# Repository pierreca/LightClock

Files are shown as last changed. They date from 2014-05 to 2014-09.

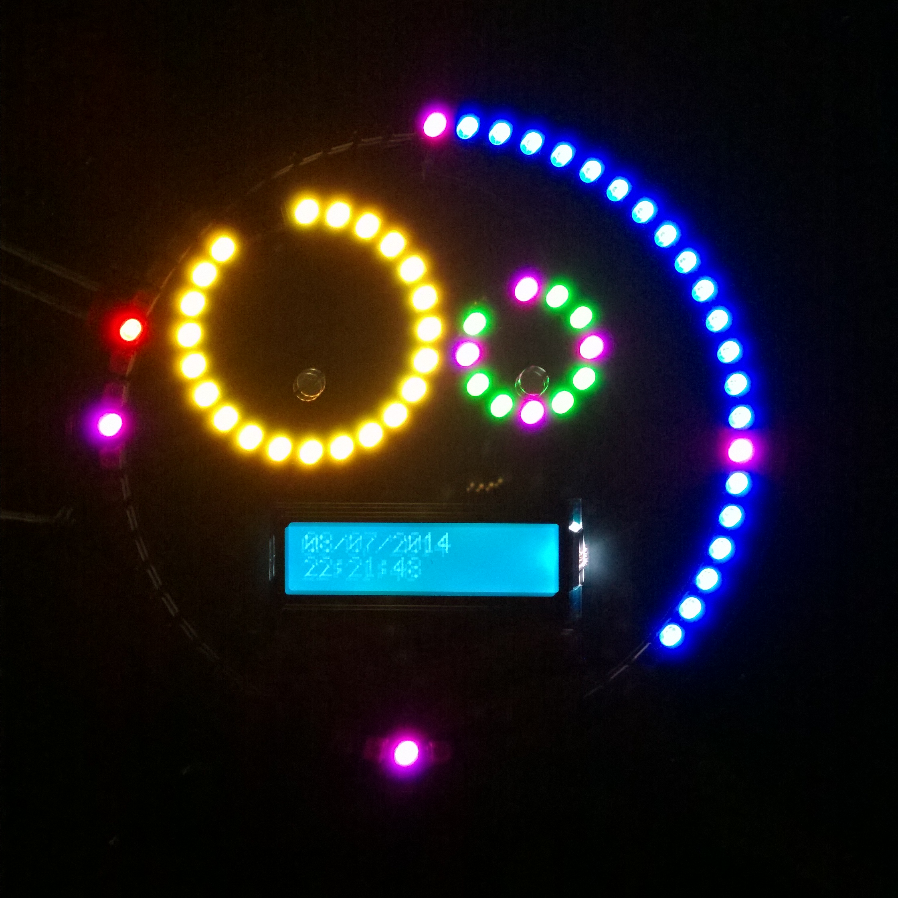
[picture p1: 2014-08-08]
blurrypic.jpg

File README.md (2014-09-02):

LightClock is a simple clock project.

LightClock Blurry Pic

#Hardware#
* [Arduino Uno R3](http://www.adafruit.com/products/50 "Arduino Uno R3")
* [LCD Shield](http://www.adafruit.com/products/714)
* Adafruit NeoPixels Rings ([12](http://www.adafruit.com/products/1643), [24](http://www.adafruit.com/products/1586) and [60](http://www.adafruit.com/products/1768) LEDs)
* [Chronodot](http://www.adafruit.com/products/255)
* [Parallax PIR Sensor](http://www.parallax.com/product/555-28027)
* [Adafruit Weatherproof Pushbutton (Momentary)](https://www.adafruit.com/products/481)
* [Adafruit Weatherproof Pushbutton (On/Off)](https://www.adafruit.com/products/915)

#Chassis#
Made of smoke laser-cut acrylic. It's a very bad design that constantly falls appart and is a pain to assemble.

#Features#
* Displays the time (it's a clock!)
	* Minutes and Seconds on the outer ring
	* Hours (on the inner rings)
	* Date and Time on the LCD screen
* Time can be set with the buttons of the LCD shield.
* Keeps time even when not plugged thanks to the Chronodot battery
* Clock stays on for 30 minutes then turns off. any movement detected by the PIR sensor will wake it up.
* Front button enables/disable wake up from PIR sensor (for night time for example)
* Back button acts as a regular on/off button

#In Progress#
(see other branches)
* PIR sensor to detect movement and light up/down
* Button to override PIR sensor

#Ideas for the future#
* Redesign chassis to be easier to assemble/disassemble and more sturdy.
* Alarm Clock (add a buzzer?)
* On/Off hours (dim or turn off at night)
* Add a potentiometer to control LEDs intensity
* Add some connectivity and a "Control app" to set things like colors and alarms.

#Links#
* <http://www.hackster.io/pierreca/lightclock>
* <https://hackaday.io/project/2330-LightClock>

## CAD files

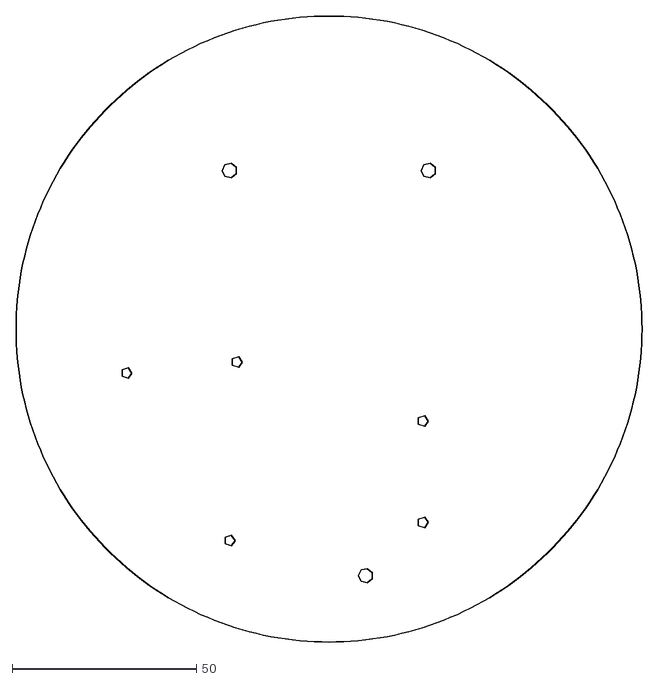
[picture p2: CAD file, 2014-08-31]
Case/Backplate.dxf
170.0 x 170.0

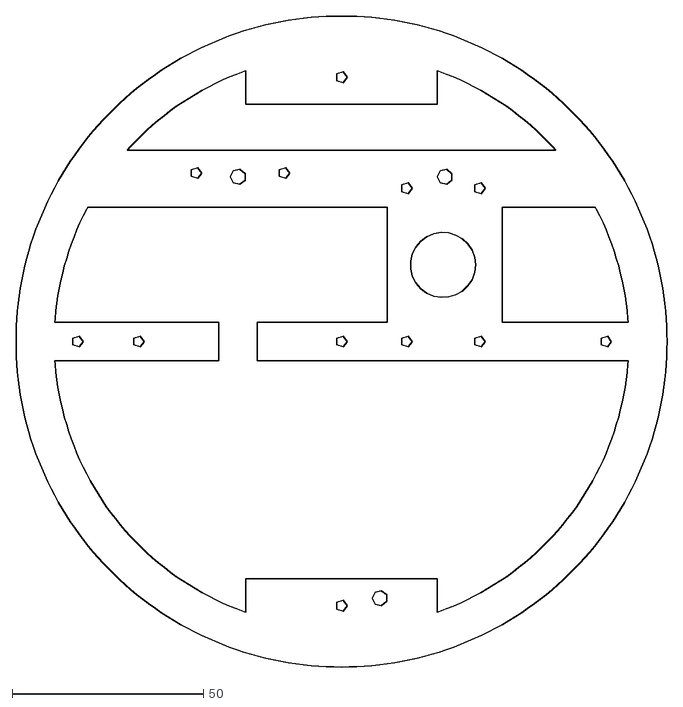
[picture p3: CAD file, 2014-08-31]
Case/RingsBackPlate.dxf
170.0 x 170.0

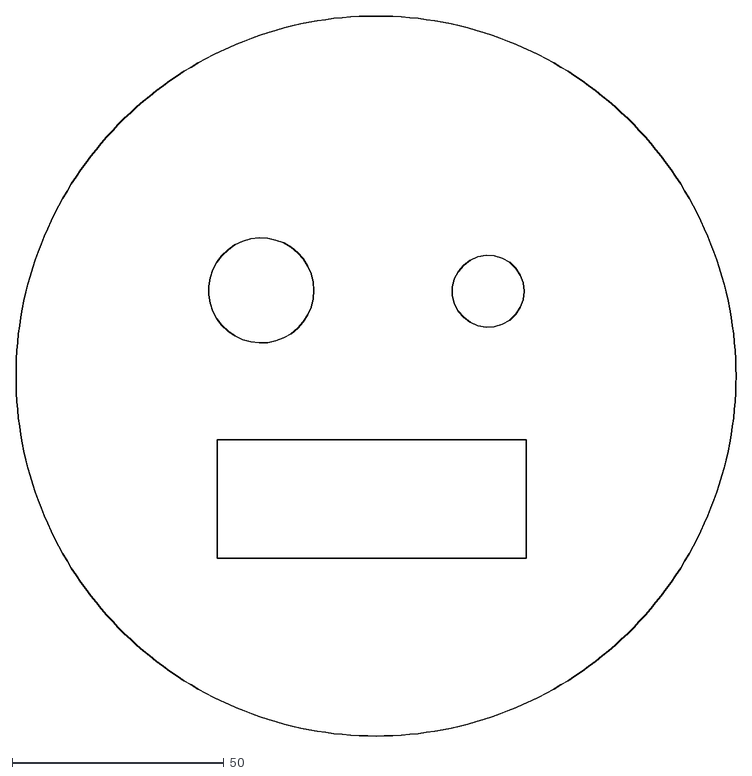
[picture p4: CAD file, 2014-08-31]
Case/Frontplate.dxf
170.0 x 170.0

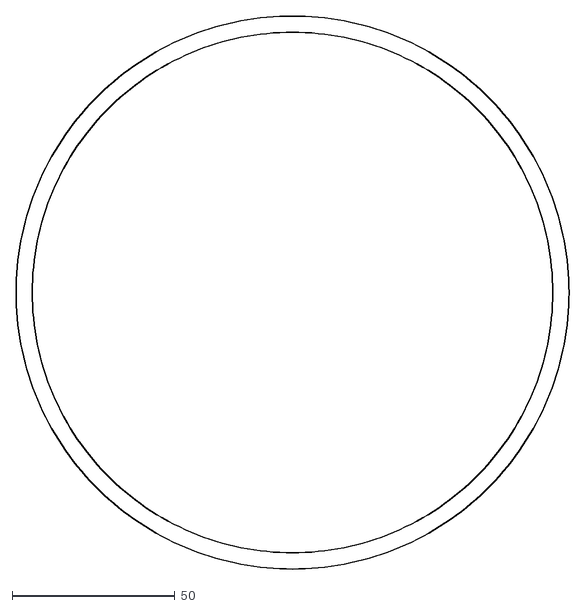
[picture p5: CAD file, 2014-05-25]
Case/SideRing.dxf
170.0 x 170.0

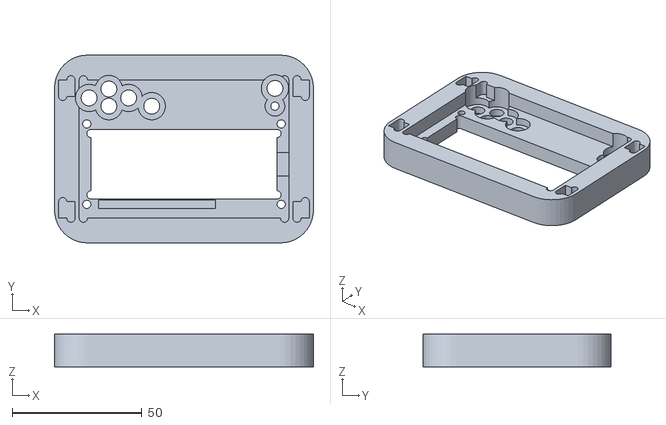
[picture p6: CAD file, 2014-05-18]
Case/faceplate.STL
99.8 x 72.4 x 12.7

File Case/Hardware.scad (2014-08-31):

// Screws and Spacers for the LightClock project
//
// Pierre Cauchois (pierreca)
// 5/18/2014

module spacer(x,y,z) {
	spacer_generic(x, y, z, 10);
}

module short_spacer(x, y, z) {
	spacer_generic(x, y, z, 3);
}

module spacer_generic(x, y, z, length) {
	color("black")
	translate([x,y,z]) {
		difference() {
			cylinder(h = length, r = 3.5);
			cylinder(h = length, r = 1.5);
		}
	}
}

module big_spacer(x,y,z) {
	color("silver")
	translate([x,y,z]) {
		difference() {
			cylinder(h = 20, r = 4.5);
			cylinder(h = 20, r = 2);
		}
	}
}

module screw (x,y,z) {
	screw_generic(x, y, z, 20);
}

module long_screw (x,y,z) {
	color("silver")
	translate([x,y,z]) {
		difference() {
			union () {
				cylinder(h = 50, r = 2);
				cylinder(h = 2.5, r = 3.5);
			}
			translate([-4, -0.5, -0.5]) cube(size=[8, 1, 1]);
		}
	}
}

module short_screw (x,y,z) {
	screw_generic(x, y, z, 8);
}

module screw_generic (x,y,z,length) {
	color("silver")
	translate([x,y,z]) {
		difference() {
			union() {
				cylinder(h = length, r = 1.5);
				cylinder(h = 2, r = 2.5);
			}
			translate([-3, -0.5, -0.5]) cube(size=[6, 1, 1]);
		}
	}
}

screw(10,0,0);
spacer(10,0,3);

long_screw(0,0,0);
big_spacer(0,0,4);

short_screw(20, 0, 0);
short_spacer(20, 0, 3);

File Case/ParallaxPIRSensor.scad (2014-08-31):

pcb_thickness = 1.75;
pcb_width = 36;
pcb_height = 25;

sensor_base_width = 23;
sensor_base_thickness = 3.2;
sensor_orb_radius = 11.4;

module pcb (x, y, z) {
	translate([x, y, z]) {
		difference() {
			color("teal") cube(size=[pcb_width, pcb_height, pcb_thickness]);		
			translate([2.5, 13, -0.5]) cylinder(h = pcb_thickness + 1, r = 1.15);
			translate([32.5, 13, -0.5]) cylinder(h = pcb_thickness + 1, r = 1.15);
		}
	}
}

module sensor (x, y, z) {
	translate([x, y, z]) {
		color("white") 
		union() {
			cube(size=[sensor_base_width, sensor_base_width, sensor_base_thickness]);
			translate([sensor_orb_radius, sensor_orb_radius, sensor_base_thickness])
			difference() {
				sphere(sensor_orb_radius); // for normal rendering
				//cylinder(h = 20, r = sensor_orb_radius); // helps for laser cutting
				translate([-(sensor_orb_radius + 0.5), -(sensor_orb_radius + 0.5), -(2*sensor_orb_radius + 1)]) cube(size=[2*sensor_orb_radius + 1, 2*sensor_orb_radius + 1, 2*sensor_orb_radius + 1]);
			}
		}		
	}
}

module jumper (x, y, z) {
	translate([x, y, z]) {	
		color("black") cube(size=[2, 6, 6]);
	}
}

module connector (x, y, z) {
	translate([x, y, z]) {	
		color("black") cube(size=[7.5, 8.5, 2]);
	}
}


module pir_sensor (x, y, z) {
	translate([x, y, z]) {
		pcb(0,0,0);
		sensor(6, 0.8, pcb_thickness);	
		jumper(1, 17, -6);	
		connector(14,-6.6,-2);
	}
}

pir_sensor(0,0,0);

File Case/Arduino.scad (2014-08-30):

// Arduino Components for the LightClock project
//
// Pierre Cauchois (pierreca)
// 5/18/2014

pcb_thickness = 1.75;

module button(x, y) {
	translate([x,y,0]) {
		color("silver") cube(size=[6, 6, 3.5]);
		color("black") translate([3, 3, 0]) cylinder(h=5, r=1.5);
	}
}

module buttons(x, y, z) {
	translate([x, y, z]) {
		button(x, y + 4);
		button(x + 8, y);
		button(x + 8, y + 7);
		button(x + 16, y + 4);
		button(x + 24, y + 7);
		button(x + 72.5, y);
	}
}

module lcd_16x2(x, y, z) {
	translate([x, y, z]) {
		color("darkgrey") difference () {
			cube(size=[73, 28, 9]);
			translate([3.5, 5, 8.6]) cube(size=[66, 18, 0.5]);
		}
		color("darkgreen") translate([3.5, 5, 8.4]) cube(size=[66, 18, 0.5]);
	}
}

module pcb(width_x, height_y) {
	color("teal") cube(size=[width_x, height_y, pcb_thickness]);
}

module arduino (x, y, z) {
	translate([x, y, z]) {
		difference() {
			pcb(68.5, 53); 	// Arduino PCB (w/ screw holes)
			translate([13.5,2.5,0]) cylinder(h=2, r=1.5);
			translate([66,7.5,0]) cylinder(h=2, r=1.5);
			translate([66,35,0]) cylinder(h=2, r=1.5);
			translate([15,51,0]) cylinder(h=2, r=1.5);
		}
		color("silver") translate([-6, 32, pcb_thickness]) cube (size=[16, 12, 11]); // USB port
		color("black") translate([-2, 1, pcb_thickness]) cube (size=[13.5, 8.5, 11]); // Power jack
		color("black") translate([26, 1, pcb_thickness]) cube (size=[21, 2.5, 8.5]); // Header
		color("black") translate([49, 1, pcb_thickness]) cube (size=[16, 2.5, 8.5]); // Header
		color("black") translate([17, 49.5, pcb_thickness]) cube (size=[26, 2.5, 8.5]); // Header
		color("black") translate([44, 49.5, pcb_thickness]) cube (size=[21, 2.5, 8.5]); // Header
	}
}

module adafruit_lcd_shield_base(x, y, z) {
	translate([x, y, z]) {
		pcb(81, 54); // base PCB
		buttons(0, 0, pcb_thickness); // buttons
	}

}

module adafruit_lcd_shield_screen() {
	pcb(81, 36); // screen PCB
	lcd_16x2(3, 3.5, 1.6); // LCD
}

module adafruit_lcd_shield_default(x, y, z) {
	translate([x, y, z]) {
		adafruit_lcd_shield_base(0, 0, 0);

		translate([0, 13.5, 3.8]) { 
			adafruit_lcd_shield_screen();
		}
	}
}

module adafruit_lcd_shield_stackable(x, y, z) {
	translate([x, y, z]) {
		adafruit_lcd_shield_base(0, 0, 0);
		color("black") translate([26, 1, pcb_thickness]) cube (size=[21, 2.5, 8.5]); // Header
		color("black") translate([49, 1, pcb_thickness]) cube (size=[16, 2.5, 8.5]); // Header
		color("black") translate([17, 49.5, pcb_thickness]) cube (size=[26, 2.5, 8.5]); // Header
		color("black") translate([44, 49.5, pcb_thickness]) cube (size=[21, 2.5, 8.5]); // Header
		rotate ([3,0,0]) translate([0, 13.5, 3]) { 
			adafruit_lcd_shield_screen();
		}
	}
}

module arduino_lcd_shield(x, y, z) {
	arduino(x, y, z);
	adafruit_lcd_shield_default(x, y, z + 13);
}

//arduino_lcd_shield(0, 0, 0);
adafruit_lcd_shield_default(0, 0, 0);

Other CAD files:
Case/Casing.scad
Case/NeoPixels.scad
Case/WaterproofPushButton.scad

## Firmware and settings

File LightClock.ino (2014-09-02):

#include <Wire.h>
#include <RTClib.h>
#include <FiniteStateMachine.h>

#include <Adafruit_MCP23017.h>
#include <Adafruit_RGBLCDShield.h>
#include <Adafruit_NeoPixel.h>

#include "LoopHelpers.h"
#include "TimeHelpers.h"

#define PIR_OVERRIDE_BUTTON_PIN 2
#define PIR_OVERRIDE_LED 7
#define PIR_PIN 3
#define PIR_CALIBRATION_SECONDS 20

#define NEO_HOUR_PIN 6
#define NEO_MINSEC_PIN 5
#define NEO_ANIM_PIN 4
#define NEO_BRIGHTNESS 64

#define OFF 0x0
#define RED 0x1
#define YELLOW 0x3
#define GREEN 0x2
#define TEAL 0x6
#define BLUE 0x4
#define VIOLET 0x5
#define WHITE 0x7

#define ROWS 2
#define COLS 16

#define DATE_STRING_LENGTH 10
#define TIME_STRING_LENGTH 8

#define TRANSITION_DELAY 300

#define AWAKE_TIME_SECONDS 1800

RTC_DS1307 rtc;

Adafruit_RGBLCDShield lcd = Adafruit_RGBLCDShield();

Adafruit_NeoPixel hourStrip = Adafruit_NeoPixel(12, NEO_HOUR_PIN, NEO_GRB + NEO_KHZ800);
Adafruit_NeoPixel minSecStrip = Adafruit_NeoPixel(60, NEO_MINSEC_PIN, NEO_GRB + NEO_KHZ800);
Adafruit_NeoPixel animStrip = Adafruit_NeoPixel(24, NEO_ANIM_PIN, NEO_GRB + NEO_KHZ800);

uint32_t neoRed = hourStrip.Color(255, 0, 0);
uint32_t neoGreen = hourStrip.Color(0, 255, 0);
uint32_t neoBlue = hourStrip.Color(0, 0, 255);
uint32_t neoMagenta = hourStrip.Color(255, 0, 255);
uint32_t neoBlack = hourStrip.Color(0, 0, 0);
uint32_t neoYellow = hourStrip.Color(255, 255, 0);

char dateString[DATE_STRING_LENGTH + 1];
char timeString[TIME_STRING_LENGTH + 1];

// FSM Definition
State ShowTime = State(showTimeEnter, showTimeUpdate, showTimeExit);
State SetDate = State(setDateEnter, setDateUpdate, setDateExit);
State SetTime = State(setTimeEnter, setTimeUpdate, setTimeExit);
State Sleeping = State(setSleepingEnter, setSleepingUpdate, setSleepingExit);

FSM clockStateMachine = FSM(ShowTime);

DateTime newDateTime;
short cursorPosition;
short maxCursorPosition;

DateTime now;
DateTime wakeUpTime;
bool  wakeUp = false;
bool pirEnabled = true;

void setup()
{
	Serial.begin(115200);
	Wire.begin();
	rtc.begin();
	lcd.begin(16, 2);
	lcd.setBacklight(WHITE);
	
	hourStrip.begin();
	hourStrip.setBrightness(NEO_BRIGHTNESS);
	hourStrip.show();

	minSecStrip.begin();
	minSecStrip.setBrightness(NEO_BRIGHTNESS);
	minSecStrip.show();

	animStrip.begin();
	animStrip.setBrightness(NEO_BRIGHTNESS);
	animStrip.show();

	if (!rtc.isrunning())
	{
		Serial.write("RTC not running!\n");
		rtc.adjust(DateTime(__DATE__, __TIME__));
	}

	pinMode(PIR_PIN, INPUT);
	pinMode(PIR_OVERRIDE_BUTTON_PIN, INPUT_PULLUP);
	pinMode(PIR_OVERRIDE_LED, OUTPUT);

	lcd.setBacklight(BLUE);

	for (int i = PIR_CALIBRATION_SECONDS; i > 0; i--)
	{
		lcd.clear();
		lcd.setCursor(0, 0);
		lcd.print("CALIBRATING PIR");
		lcd.setCursor(0, 1);
		lcd.print(i);
		delay(1000);
	}
	
	lcd.clear();
	lcd.setBacklight(GREEN);
	lcd.setCursor(0, 0);
	lcd.print("DONE!");

	delay(1000);

	now = rtc.now();
	wakeUpTime = rtc.now();
}

void loop()
{
	if (digitalRead(PIR_OVERRIDE_BUTTON_PIN) == LOW)
	{
		pirEnabled = !pirEnabled;

		if (clockStateMachine.isInState(Sleeping)) {
			wakeUp = true;
		} 
		else
		{
			wakeUp = false;
			clockStateMachine.transitionTo(Sleeping);
		}

		delay(300);
	}

	digitalWrite(PIR_OVERRIDE_LED, pirEnabled);

	uint8_t buttons = lcd.readButtons();

	if (buttons & BUTTON_SELECT) 
	{
		if (clockStateMachine.isInState(ShowTime))
		{
			clockStateMachine.transitionTo(SetDate);
		}
		else if (clockStateMachine.isInState(SetDate) && isDateValid(dateString))
		{
			clockStateMachine.transitionTo(SetTime);
		}
		else if (clockStateMachine.isInState(SetTime) && isTimeValid(timeString))
		{
			clockStateMachine.transitionTo(ShowTime);
		}

		delay(TRANSITION_DELAY);
	}

	if (clockStateMachine.isInState(Sleeping) && wakeUp)
	{
		wakeUpTime = rtc.now();
		clockStateMachine.transitionTo(ShowTime);
	}
	else if (clockStateMachine.isInState(ShowTime))
	{
		long secondsDiff = now.unixtime() - wakeUpTime.unixtime();
		if (secondsDiff >= AWAKE_TIME_SECONDS)
		{
			wakeUp = false;
			clockStateMachine.transitionTo(Sleeping);
		}
	}

	clockStateMachine.update();
}

void setNeoPixels(DateTime time)
{
	uint16_t h = time.hour() < 12 ? time.hour() : time.hour() - 12;
	uint16_t m = time.minute();
	uint16_t s = time.second();

        for (uint16_t i = 0; i < time.hour(); i++)
        {
                animStrip.setPixelColor(i, neoYellow);
        }

	for (uint16_t i = 0; i <= h; i++)
	{
		hourStrip.setPixelColor(i, neoGreen);
	}

	if (h != 0)
		hourStrip.setPixelColor(0, neoMagenta);

	if (h != 3)
		hourStrip.setPixelColor(3, neoMagenta);

	if (h != 6)
		hourStrip.setPixelColor(6, neoMagenta);

	if (h != 9)
		hourStrip.setPixelColor(9, neoMagenta);

	for (uint16_t i = 0; i <= m; i++)
	{
		if (i != s && i != 0 && i != 15 && i != 30 && i != 45)
		{
			minSecStrip.setPixelColor(i, neoBlue);
		}
	}

	for (uint16_t i = m + 1; i < 60; i++)
	{
		minSecStrip.setPixelColor(i, neoBlack);
	}

	minSecStrip.setPixelColor(0, neoMagenta);
	minSecStrip.setPixelColor(15, neoMagenta);
	minSecStrip.setPixelColor(30, neoMagenta);
	minSecStrip.setPixelColor(45, neoMagenta);

	minSecStrip.setPixelColor(time.second(), neoRed);

	showStrips();
}

void showStrips()
{
	hourStrip.show();
	minSecStrip.show();
    animStrip.show();
}


void showTimeEnter()
{
	lcd.noCursor();
	lcd.noBlink();
	lcd.setBacklight(WHITE);
}

void showTimeUpdate()
{
	now = rtc.now();

	sprintf(dateString, "%02d/%02d/%d", now.month(), now.day(), now.year());
	sprintf(timeString, "%02d:%02d:%02d", now.hour(), now.minute(), now.second());

	lcd.setCursor(0, 0);
	lcd.print(dateString);

	lcd.setCursor(0, 1);
	lcd.print(timeString);

	setNeoPixels(now);
}

void showTimeExit() 
{

}

void setDateEnter()
{
	lcd.clear();
	lcd.setBacklight(GREEN);
	lcd.setCursor(0, 0);
	lcd.print("SET DATE:");
	lcd.setCursor(0, 1);
	newDateTime = rtc.now();
	sprintf(dateString, "%02d/%02d/%04d", newDateTime.month(), newDateTime.day(), newDateTime.year());
	lcd.print(dateString);

	cursorPosition = 1;
	maxCursorPosition = DATE_STRING_LENGTH - 1;

	lcd.setCursor(1, 1);
	lcd.cursor();
}

void setDateUpdate()
{
	uint8_t buttons = lcd.readButtons();

	char dayString[3] = { dateString[3], dateString[4], '\0' };
	char monthString[3] = { dateString[0], dateString[1], '\0' };
	char yearString[5] = { dateString[6], dateString[7], dateString[8], dateString[9], '\0' };

	int day = atoi(dayString);
	int month = atoi(monthString);
	int year = atoi(yearString);

	bool dateChanged = false;
	bool cursorChanged = false;

	if ((buttons & BUTTON_RIGHT) && (cursorPosition < maxCursorPosition))
	{
		delay(TRANSITION_DELAY);
		Serial.write("right\n");
		if (cursorPosition == 1)
		{
			cursorPosition = 4;
		}
		else if (cursorPosition == 4)
		{
			cursorPosition = 9;
		}
		else
		{
			cursorPosition = 1;
		}

		cursorChanged = true;
	}
	else if ((buttons & BUTTON_LEFT) && (cursorPosition > 0))
	{
		delay(TRANSITION_DELAY);
		Serial.write("left\n");
		if (cursorPosition == 9)
		{
			cursorPosition = 4;
		}
		else if (cursorPosition == 4)
		{
			cursorPosition = 1;
		}
		else
		{
			cursorPosition = 9;
		}

		cursorChanged = true;
	}
	else if (buttons & BUTTON_UP)
	{
		delay(TRANSITION_DELAY);
		Serial.write("up\n");

		switch (cursorPosition)
		{
		case 1:
			month = incrementOrLoop(month, 12, 1);
			break;
		case 4:
			if (month == 2)
			{
				if (year % 4 == 0)
				{
					day = incrementOrLoop(day, 29, 1);
				}
				else
				{
					day = incrementOrLoop(day, 28, 1);
				}
			}
			else if (month == 1
				|| month == 3
				|| month == 5
				|| month == 7
				|| month == 8
				|| month == 10
				|| month == 12)
			{
				day = incrementOrLoop(day, 31, 1);
			}
			else
			{
				day = incrementOrLoop(day, 30, 1);
			}
			break;
		case 9:
			year = incrementOrLoop(year, 9999);
			break;
		default:
			break;
		}

		dateChanged = true;
	}
	else if (buttons & BUTTON_DOWN)
	{
		delay(TRANSITION_DELAY);
		Serial.write("down\n");

		switch (cursorPosition)
		{
		case 1:
			month = decrementOrLoop(month, 12, 1);
			break;
		case 4:
			if (month == 2)
			{
				if (year % 4 == 0)
				{
					day = decrementOrLoop(day, 29, 1);
				}
				else
				{
					day = decrementOrLoop(day, 28, 1);
				}
			}
			else if (month == 1
				|| month == 3
				|| month == 5
				|| month == 7
				|| month == 8
				|| month == 10
				|| month == 12)
			{
				day = decrementOrLoop(day, 31, 1);
			}
			else
			{
				day = decrementOrLoop(day, 30, 1);
			}
			break;
		case 9:
			year = decrementOrLoop(year, 9999);
			break;
		default:
			break;
		}

		dateChanged = true;
	}

	if (dateChanged)
	{
		sprintf(dateString, "%02d/%02d/%04d", month, day, year);

		if (!isDateValid(day, month, year))
		{
			lcd.setBacklight(RED);
		}
		else
		{
			lcd.setBacklight(GREEN);
		}

		lcd.setCursor(0, 1);
		lcd.print(dateString);

		dateChanged = false;
		cursorChanged = true;
	}

	if (cursorChanged == true)
	{
		lcd.setCursor(cursorPosition, 1);
		cursorChanged = false;
	}
}

void setDateExit()
{
	
}

void setTimeEnter()
{
	lcd.clear();
	lcd.setBacklight(GREEN);
	lcd.setCursor(0, 0);
	lcd.print("SET TIME:");
	lcd.setCursor(0, 1);

	newDateTime = rtc.now();
	sprintf(timeString, "%02d:%02d:%02d", newDateTime.hour(), newDateTime.minute(), newDateTime.second());
	lcd.print(timeString);

	cursorPosition = 1;
	maxCursorPosition = TIME_STRING_LENGTH - 1;

	lcd.setCursor(1, 1);
	lcd.cursor();
}

void setTimeUpdate()
{
	char hourString[3] = { timeString[0], timeString[1], '\0' };
	char minuteString[3] = { timeString[3], timeString[4], '\0' };
	char secondString[5] = { timeString[6], timeString[7], '\0' };

	int hour = atoi(hourString);
	int minute = atoi(minuteString);
	int second = atoi(secondString);

	bool timeChanged = false;
	bool cursorChanged = false;

	uint8_t buttons = lcd.readButtons();

	if ((buttons & BUTTON_RIGHT) && (cursorPosition < maxCursorPosition))
	{
		delay(TRANSITION_DELAY);
		Serial.write("right\n");
		if (cursorPosition == 1)
		{
			cursorPosition = 4;
		}
		else if (cursorPosition == 4)
		{
			cursorPosition = 7;
		}
		else
		{
			cursorPosition = 1;
		}

		cursorChanged = true;
	}
	else if ((buttons & BUTTON_LEFT) && (cursorPosition > 0))
	{
		delay(TRANSITION_DELAY);
		Serial.write("left\n");
		if (cursorPosition == 7)
		{
			cursorPosition = 4;
		}
		else if (cursorPosition == 4)
		{
			cursorPosition = 1;
		}
		else
		{
			cursorPosition = 7;
		}

		cursorChanged = true;
	}
	else if (buttons & BUTTON_UP)
	{
		delay(TRANSITION_DELAY);
		Serial.write("up\n");

		switch (cursorPosition)
		{
		case 1:
			hour = incrementOrLoop(hour, 23);
			break;
		case 4:
			minute = incrementOrLoop(minute, 60);
			break;
		case 9:
			second = incrementOrLoop(second, 60);
			break;
		default:
			break;
		}

		timeChanged = true;
	}
	else if (buttons & BUTTON_DOWN)
	{
		delay(TRANSITION_DELAY);
		Serial.write("down\n");

		switch (cursorPosition)
		{
		case 1:
			hour = decrementOrLoop(hour, 23);
			break;
		case 4:
			minute = decrementOrLoop(minute, 60);
			break;
		case 9:
			second = decrementOrLoop(second, 60);
			break;
		default:
			break;
		}

		timeChanged = true;
	}


	if (timeChanged)
	{
		sprintf(timeString, "%02d:%02d:%02d", hour, minute, second);

		if (!isTimeValid(hour, minute, second))
		{
			lcd.setBacklight(RED);
		}
		else
		{
			lcd.setBacklight(GREEN);
		}

		lcd.setCursor(0, 1);
		lcd.print(timeString);

		timeChanged = false;
		cursorChanged = true;
	}

	if (cursorChanged == true)
	{
		lcd.setCursor(cursorPosition, 1);
		cursorChanged = false;
	}
}

void setTimeExit()
{

	char dayString[3] = { dateString[3], dateString[4], '\0' };
	char monthString[3] = { dateString[0], dateString[1], '\0' };
	char yearString[5] = { dateString[6], dateString[7], dateString[8], dateString[9], '\0' };

	char hourString[3] = { timeString[0], timeString[1], '\0' };
	char minuteString[3] = { timeString[3], timeString[4], '\0' };
	char secondString[5] = { timeString[6], timeString[7], '\0' };

	int day = atoi(dayString);
	int month = atoi(monthString);
	int year = atoi(yearString);

	int hour = atoi(hourString);
	int minute = atoi(minuteString);
	int second = atoi(secondString);

	rtc.adjust(DateTime(year, month, day, hour, minute, second));
}

void setSleepingEnter()
{
	lcd.clear();
	lcd.setBacklight(RED);
	lcd.setCursor(0, 0);
	lcd.print("GOING TO SLEEP");
	delay(1000);
	turnOffStrips();
	lcd.setBacklight(OFF);
	lcd.clear();
}

void setSleepingExit()
{
	lcd.clear();
	lcd.setBacklight(RED);
	lcd.setCursor(0, 0);
	lcd.print("WAKING UP...");
	delay(1000);
	turnOnStrips();
}

void setSleepingUpdate()
{
	if (pirEnabled && digitalRead(PIR_PIN) == HIGH)
	{
		wakeUp = true;
	}
}

void turnOffStrips()
{
	animStrip.setBrightness(0);
	hourStrip.setBrightness(0);
	minSecStrip.setBrightness(0);

	showStrips();
}

void turnOnStrips()
{
	animStrip.setBrightness(NEO_BRIGHTNESS);
	hourStrip.setBrightness(NEO_BRIGHTNESS);
	minSecStrip.setBrightness(NEO_BRIGHTNESS);

	showStrips();
}

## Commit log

2014-05-19 Much better casing design
    Split the design into 4 different files
    All dimensions are much more precise
    Started the circuit design with Fritzing… more for documenting purpose
    than anything else
    [Arduino.scad, Casing.scad, Hardware.scad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]
2014-05-21 Adding the "eyes" holding plate
    new support for the smaller “eye” rings.
    [Casing.scad, NeoPixels.scad]
2014-05-24 Changed design to hold LED rings together
    [Casing.scad]
2014-05-25 adding DXF files as sent to Metrix on 2014/5/24 5:10pm
    [Backplate.dxf, Frontplate.dxf]
2014-05-25 adding ring mounting plates
    [RingsBackPlate.dxf, SideRing.dxf]
2014-08-08 added support for the 24 LED Ring
2014-08-26 New schematic to include PIR and switches
    [LightClock.fzz]
2014-08-29 update of the OpenScad files - buttons - PIR sensor - new LCD shield without stacking headers
    [Arduino.scad, ParallaxPIRSensor.scad, WaterproofPushButton.scad]
2014-08-30 PIR override button (untested - temporary)
2014-08-30 add PIR override LED - untested
2014-08-30 first batch of changes for the enclosure missing: new screws and spacers placement
    [Arduino.scad, Casing.scad, ParallaxPIRSensor.scad]
2014-08-31 New enclosure tentative, not validated yet
    [Backplate.dxf, Casing.scad, Frontplate.dxf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]
2014-09-02 bug corrections - v2 complete
    [Casing.scad]
